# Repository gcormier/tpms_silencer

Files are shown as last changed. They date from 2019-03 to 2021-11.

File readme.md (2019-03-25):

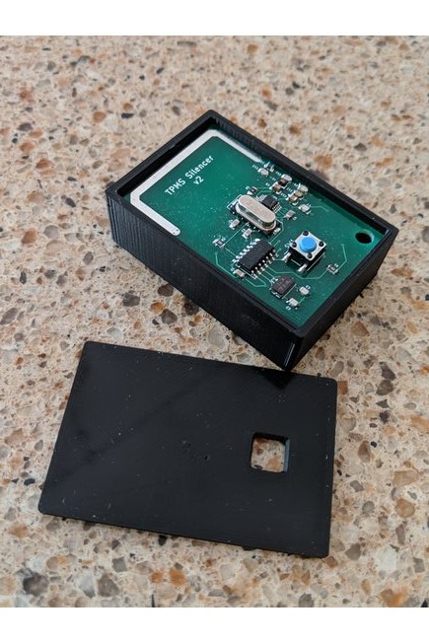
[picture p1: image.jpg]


# tpms_silencer
Open hardware that supports ASK/FSK transmit on 315/433MHz ISM bands. General point is to spoof TPMS sensors but
it could be used for any type of ASK/FSK transmittion on bands supported by the IC.

Big thanks to <a href="https://github.com/merbanan/rtl_433">rtl_433</a> project, wouldn't exist without their hard work for
decoding the TPMS in the first place.

## Availability
Boards are for sale https://www.tindie.com/products/gcormier/tpms-silencer/

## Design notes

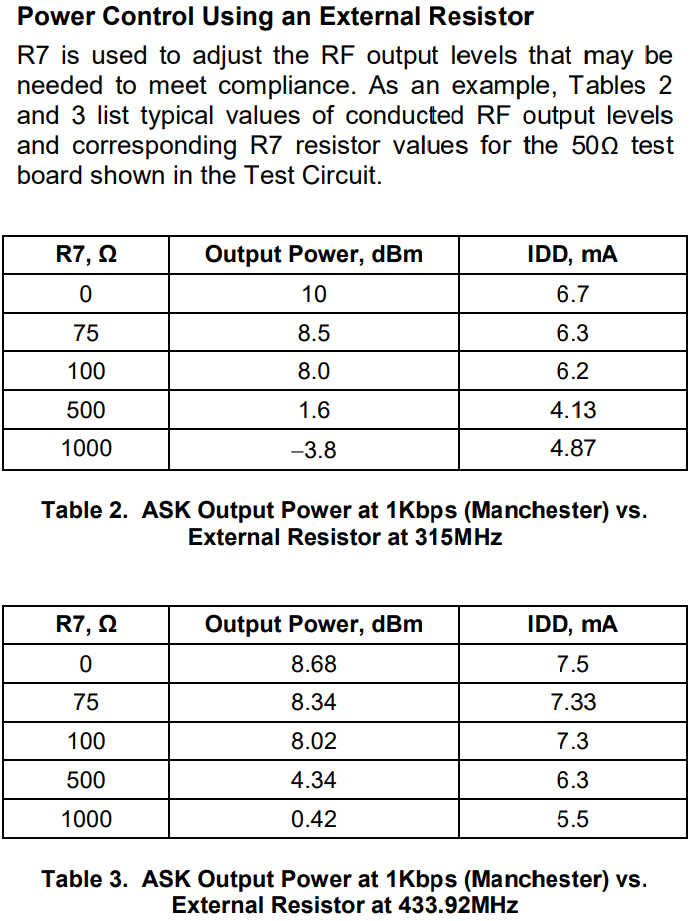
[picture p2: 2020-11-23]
PCB/values2.png

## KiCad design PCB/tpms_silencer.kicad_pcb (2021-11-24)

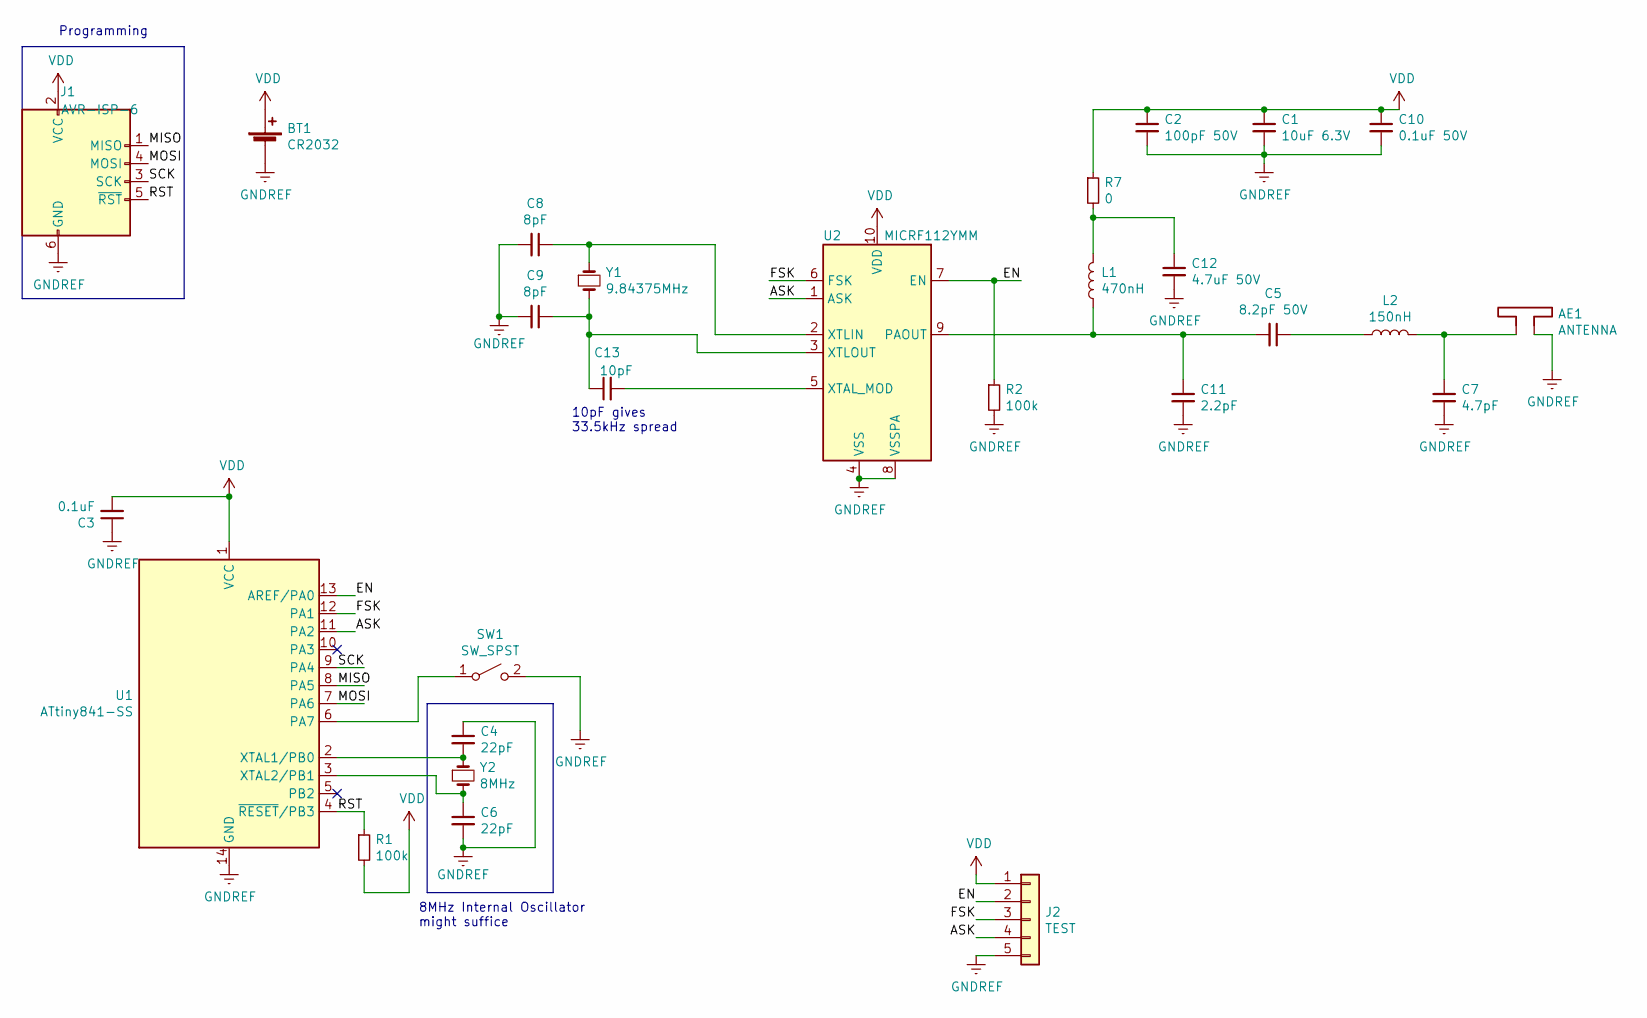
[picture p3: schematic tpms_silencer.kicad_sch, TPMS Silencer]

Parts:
AE1: ANTENNA; 315MHz Antenna
BT1: CR2032; BatteryHolder_Keystone_3034_1x20mm
C1: 10uF 6.3V; C_0805_2012Metric
C2: 100pF 50V; C_0805_2012Metric
C3: 0.1uF; C_0805_2012Metric
C4, C6: 22pF; C_0805_2012Metric
C5: 8.2pF 50V; C_0805_2012Metric
C7: 4.7pF; C_0805_2012Metric
C8, C9: 8pF; C_0805_2012Metric
C10: 0.1uF 50V; C_0805_2012Metric
C11: 2.2pF; C_0805_2012Metric
C12: 4.7uF 50V; C_0805_2012Metric
C13: 10pF; C_0805_2012Metric
J1: AVR-ISP-6; AVR-SMD-Programming-Header
J2: TEST; PinHeader_1x05_P2.54mm_Horizontal
L1: 470nH; L_0805_2012Metric
L2: 150nH; L_0805_2012Metric
R1, R2: 100k; R_0805_2012Metric
R7: 0; R_0805_2012Metric
SW1: SW_SPST; SW_SPST_PTS645
U1: ATtiny841-SS; SOIC-14_3.9x8.7mm_P1.27mm
U2: MICRF112YMM; MSOP-10_3x3mm_P0.5mm
Y1: 9.84375MHz; Crystal_SMD_HC49-SD
Y2: 8MHz; Crystal_SMD_TXC_7A-2Pin_5x3.2mm

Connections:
/ASK: J2.4, U1.11 (PA2), U2.1 (ASK)
/EN: J2.2, R2.1, U1.13 (AREF/PA0), U2.7 (EN)
/FSK: J2.3, U1.12 (PA1), U2.6 (FSK)
/MISO: J1.1 (MISO), U1.8 (PA5)
/MOSI: J1.4 (MOSI), U1.7 (PA6)
/RST: J1.5 (~RST), R1.1, U1.4 (~RESET/PB3)
/SCK: J1.3 (SCK), U1.9 (PA4)
GNDREF: AE1.2, BT1.2 (-), C1.2, C2.2, C3.1, C4.1, C6.2, C7.2, C8.2, C9.2, C10.2, C11.2, C12.2, J1.6 (GND), J2.5, R2.2, SW1.2 (B), U1.14 (GND), U2.4 (VSS), U2.8 (VSSPA)
unnamed: AE1.1, C7.1, L2.2
unnamed: C4.2, U1.2 (XTAL1/PB0), Y2.1
unnamed: C5.1, L2.1
unnamed: C6.1, U1.3 (XTAL2/PB1), Y2.2
unnamed: C8.1, U2.2 (XTLIN), Y1.1
unnamed: C5.2, C11.1, L1.1, U2.9 (PAOUT)
unnamed: C12.1, L1.2, R7.2
unnamed: C9.1, C13.1, U2.3 (XTLOUT), Y1.2
unnamed: C13.2, U2.5 (XTAL_MOD)
unnamed: SW1.1 (A), U1.6 (PA7)
VDD: BT1.1 (+), C1.1, C2.1, C3.2, C10.1, J1.2 (VCC), J2.1, R1.2, R7.1, U1.1 (VCC), U2.10 (VDD)

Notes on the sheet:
10pF gives 33.5kHz spread
8MHz Internal Oscillator might suffice
Programming

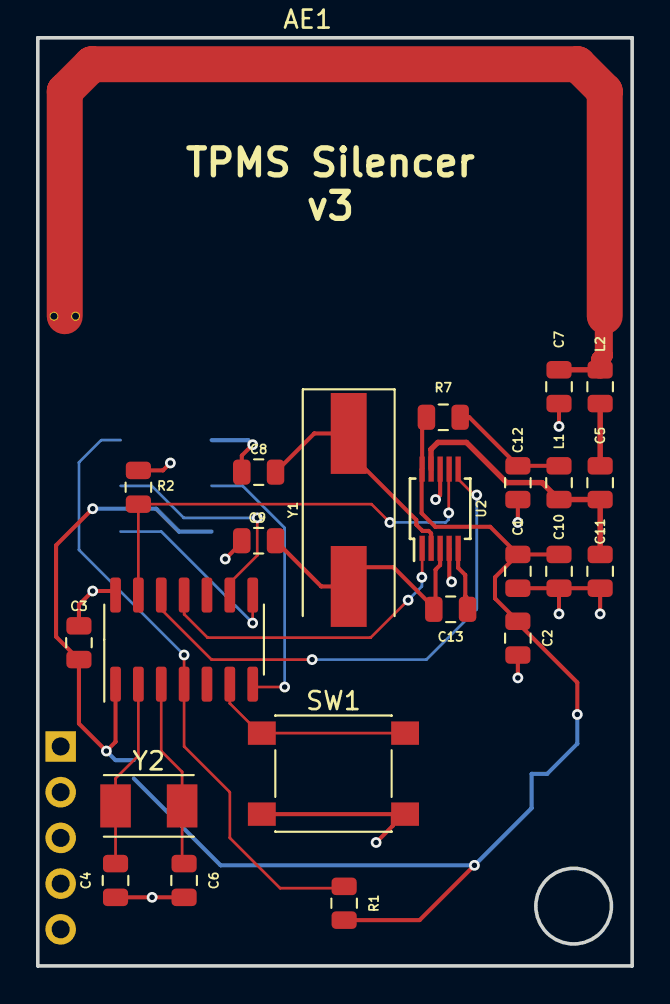
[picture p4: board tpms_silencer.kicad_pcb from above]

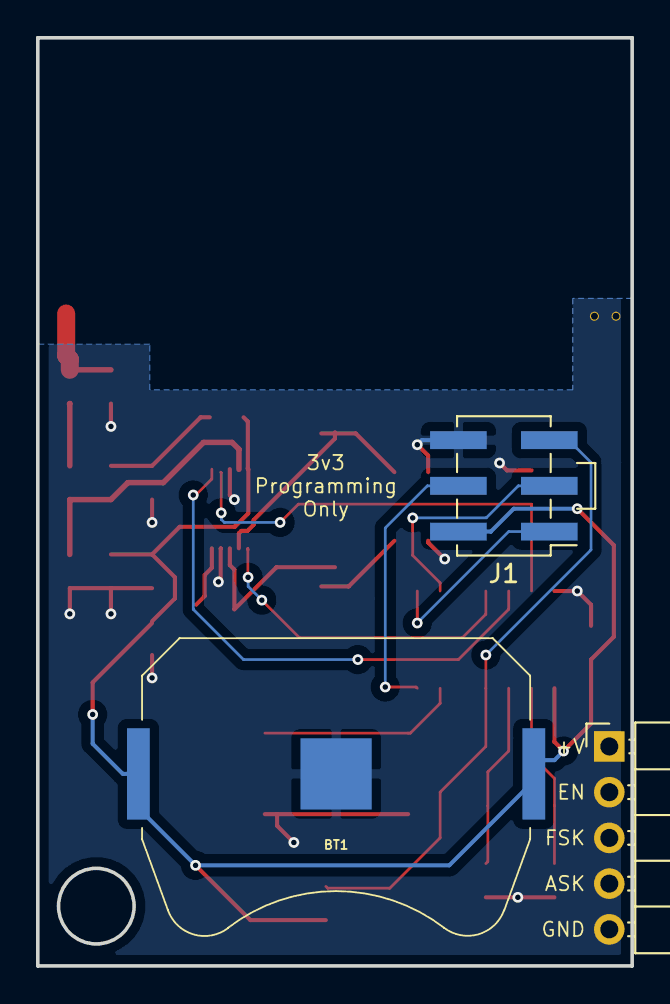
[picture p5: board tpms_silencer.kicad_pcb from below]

Board: 2 copper layers, 33.0 x 51.6 mm, 27 parts (3 on the bottom side), 19 nets.

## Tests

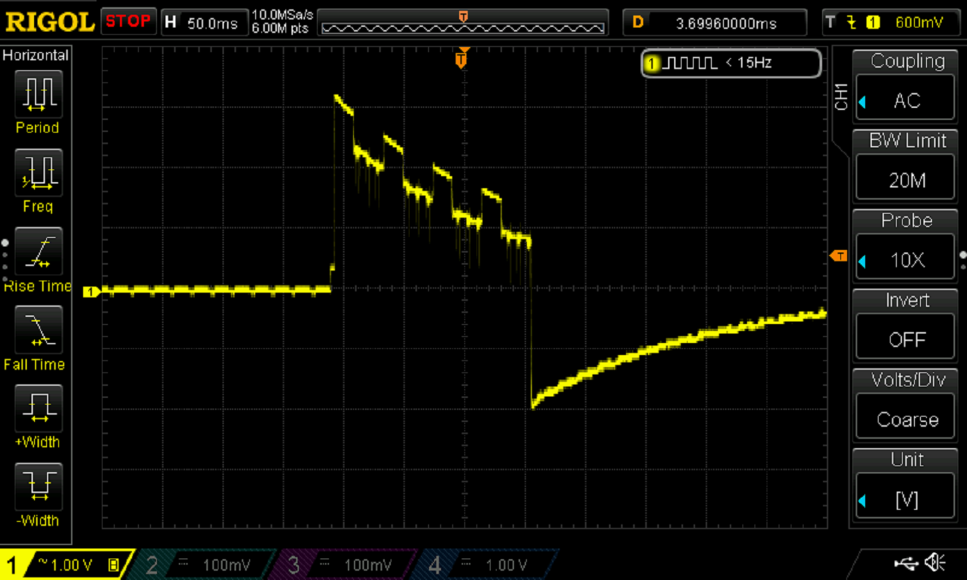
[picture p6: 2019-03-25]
Current Measurement.png

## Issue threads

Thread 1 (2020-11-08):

How to capture new TPMS data

StavJi, 2020-11-08:
Hello,

trying to decode raw data using rtl_433 SW. This is what I am sending: "111111001100110101010101010101010100101010110100110101001011001010101101010100101010101101010100110011010011010010101011010101001100110100101100"

On picture what I am decoding. I noticed that rtl trying to use PWM modulations but it should be FSK. Can you explain to me how to get back to your data? I supposed that you somehow captured TPMS message from car and I want to know how did you do that? Thank you for your help.

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

gcormier, 2020-11-08:
I captured using rtl_433 - https://github.com/merbanan/rtl_433/issues/821

I merely replay the encoded bitstream with tpms_silencer - I don't do any actual Manchester encoding on the transmitter. So you will want the raw-bitstream from rtl_433.

StavJi, 2020-11-21:
I figure it out, problem was that your sensors uses baudrate of 10000 so to capture raw bitstream using rtl_433 you need to use command: rtl_433 -R 0 -X "n=tpms,m=FSK_PCM,s=100,l=100,r=250". I think more common (my case) is sensors with baudrate 20000 so cmd will be: rtl_433 -R 0 -X "n=tpms,m=FSK_PCM,s=52,l=52,r=150".

Closed 2020-11-21.

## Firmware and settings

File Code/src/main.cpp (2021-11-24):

#include <avr/wdt.h>
#include <avr/power.h>
#include <avr/sleep.h>
#include <Arduino.h>
#include "tpms_silencer.h"

/*
Each bit/symbol: 0/1 is 100us long. sent at a rate of 10kHz
144 symbols sent in each TPMS packet: taking 14.4ms (+ 200us warmup)
All Packets are sent 40ms apart, then we deep-sleep.
If PERIODIC_TX is defined then wakeup after 7s * wakeuplimit (which is potentially variable)
BACKOFF will double the retransmit period each time until MAX_LIMIT.
*/

#define PIN_EN     A0  // PA0, Pin 13, Arduino 10
#define PIN_FSK    A1 // PA1, Pin 12, Arduino 9
#define PIN_ASK    A2 // PA2, Pin 11, Arduino 8
#define PIN_BUTTON A7 // PA7, Pin 6, PCINT7
#define INTERRUPT_PIN PCINT7 // interrupt for PA7

#define PERIODIC_TX // periodic retransmissions. disable for button-press tx only
//#define BACKOFF    // double transmit period everytime? disable to have a fixed period retrans.

#define ENHIGH (bitSet(PORTA, 0))
#define ENLOW (bitClear(PORTA, 0))

#define ASKHIGH (bitSet(PORTA, 2))
#define ASKLOW (bitClear(PORTA, 2))

#define FSKHIGH (bitSet(PORTA, 1))
#define FSKLOW (bitClear(PORTA, 1))
#define FSKTOGGLE (PORTA = PORTA ^ _BV(1))


#define PACKET_DELAY   40 // Milliseconds inter-packet period
#ifdef BACKOFF
#define LIMIT_START     1 // (re-transmit intervals: 14s, 28s, 56s, ..., MAX_LIMIT/7)
//#define MAX_LIMIT      80 // 80 max limit ~ 10mins.
#define MAX_LIMIT     160 // 160 max limit ~ 20 mins.
//#define MAX_LIMIT  0xffff // uint16_t max limit ~ 5 days.
#else
//#define LIMIT_START     8 //   8*(7s) = ~60s wakeups to transmit
#define LIMIT_START     120 // 120*(7s) = ~15mins wakeups to transmit
#endif

/*
captured tpms data: with rtl_433 -vv ...
time      : 2021-10-22 18:46:04
model     : PMV-107J     type      : TPMS          id        : 07698722
status    : 16           battery_ok: 1             counter   : 2             failed    : OK            pressure_kPa: 228.160     temperature_C: 13.000     mic       : CRC
pulse_demod_pcm(): PMV-107J (Toyota) TPMS
bitbuffer:: Number of rows: 1 
[00] {143} fc b3 4d 2b 2a b3 52 ad 4a ad 54 ab 32 ca cb 4d 2c ac 
_ _ _ _ _ _ _ _ _ _ _ _ _ _ _ _ _ _ _ _ _ _ _ _ _ _ _ _ _ _ _ _ _ _ _ _ _ _ _ _ _ _ _ _ _ _ _ _ _ _ _ _ _ _ _ _ _ _ _ _ _ _ _ _ _ _ _ _ _ _ _ _ _ _ _ _ _ _ _ _ _ _ _ _ _ _ _ _ _ _ _ _ _ _ _ _ _ _ _ _ _ _ _ _ _ _ _ _ _ _ _ _ _ _ _ _ _ _ _ _ _ _ _ _ _ _ _ _ _ _ _ _ _ _ _ _ _ _ _ _ _ _ _ _ _ _ _ _ _ _ _ _ _ _ _ _ _ _ _ _ 
time      : 2021-10-22 18:46:13
model     : PMV-107J     type      : TPMS          id        : 0805a722
status    : 24           battery_ok: 1             counter   : 3             failed    : OK            pressure_kPa: 220.720     temperature_C: 13.000     mic       : CRC
pulse_demod_pcm(): PMV-107J (Toyota) TPMS
bitbuffer:: Number of rows: 1 
[00] {143} fc d5 55 4b 2d 4c ad 52 b2 ad 55 4b 33 2a cb 4c cd 4c 
_ _ _ _ _ _ _ _ _ _ _ _ _ _ _ _ _ _ _ _ _ _ _ _ _ _ _ _ _ _ _ _ _ _ _ _ _ _ _ _ _ _ _ _ _ _ _ _ _ _ _ _ _ _ _ _ _ _ _ _ _ _ _ _ _ _ _ _ _ _ _ _ _ _ _ _ _ _ _ _ _ _ _ _ _ _ _ _ _ _ _ _ _ _ _ _ _ _ _ _ _ _ _ _ _ _ _ _ _ _ _ _ _ _ _ _ _ _ _ _ _ _ _ _ _ _ _ _ _ _ _ _ _ _ _ _ _ _ _ _ _ _ _ _ _ _ _ _ _ _ _ _ _ _ _ _ _ _ _ _ 
time      : 2021-10-22 18:46:14
model     : PMV-107J     type      : TPMS          id        : 0f536702
status    : 16           battery_ok: 1             counter   : 2             failed    : OK            pressure_kPa: 218.240     temperature_C: 13.000     mic       : CRC
pulse_demod_pcm(): PMV-107J (Toyota) TPMS
bitbuffer:: Number of rows: 1 
[00] {144} fc cc b4 ac b2 b3 55 52 b5 52 aa ab 33 35 34 b3 53 2c 
_ _ _ _ _ _ _ _ _ _ _ _ _ _ _ _ _ _ _ _ _ _ _ _ _ _ _ _ _ _ _ _ _ _ _ _ _ _ _ _ _ _ _ _ _ _ _ _ _ _ _ _ _ _ _ _ _ _ _ _ _ _ _ _ _ _ _ _ _ _ _ _ _ _ _ _ _ _ _ _ _ _ _ _ _ _ _ _ _ _ _ _ _ _ _ _ _ _ _ _ _ _ _ _ _ _ _ _ _ _ _ _ _ _ _ _ _ _ _ _ _ _ _ _ _ _ _ _ _ _ _ _ _ _ _ _ _ _ _ _ _ _ _ _ _ _ _ _ _ _ _ _ _ _ _ _ _ _ _ _ 
time      : 2021-10-22 18:46:14
model     : PMV-107J     type      : TPMS          id        : 00a89722
status    : 8            battery_ok: 1             counter   : 1             failed    : OK            pressure_kPa: 230.640     temperature_C: 14.000     mic       : CRC
pulse_demod_pcm(): PMV-107J (Toyota) TPMS
bitbuffer:: Number of rows: 1 
[00] {144} fc aa d2 d5 2b 4c ad 52 ad 52 ab 4b 32 d5 34 d5 2b 2c

*/


// Use the compact encoding reported by rtl_433 -vv  <-f 315M -R 110>
// could halve this by storing the Differential-Manchester decoded values...
// Or even better generate packets on the fly, based on id, pressure/temp, etc.
#define NO_PACKETS      4
#define PACKET_LEN     18
#define PACKETSIZE    (PACKET_LEN*8) // 144 bits
const unsigned char packets[NO_PACKETS][PACKET_LEN] = { 
  // packet 0
  { 0xfc, 0xb3, 0x4d, 0x2b, 0x2a, 0xb3, 0x52, 0xad, 0x4a, 0xad, 0x54, 0xab, 0x32, 0xca, 0xcb, 0x4d, 0x2c, 0xac},
  // packet 1
  { 0xfc, 0xd5, 0x55, 0x4b, 0x2d, 0x4c, 0xad, 0x52, 0xb2, 0xad, 0x55, 0x4b, 0x33, 0x2a, 0xcb, 0x4c, 0xcd, 0x4c},
  // packet 2
  { 0xfc, 0xcc, 0xb4, 0xac, 0xb2, 0xb3, 0x55, 0x52, 0xb5, 0x52, 0xaa, 0xab, 0x33, 0x35, 0x34, 0xb3, 0x53, 0x2c},
  // packet 3
  { 0xfc, 0xaa, 0xd2, 0xd5, 0x2b, 0x4c, 0xad, 0x52, 0xad, 0x52, 0xab, 0x4b, 0x32, 0xd5, 0x34, 0xd5, 0x2b, 0x2c} };

volatile unsigned char packet=0; // which packet is being sent 0 - NO_PACKETS-1
volatile unsigned int currentBit; // which bit in that packet is next

volatile bool transmitting = false; // indicates if transmitting a packet

volatile unsigned int wakeupCounter = 0; // how many 8s watchdog timeouts since last transmit
volatile unsigned int wakeuplimit = LIMIT_START;  // How many 8-second wakeups before transmit again


// setup functions

// 10khz Interrupt for an 8MHz clock
void setupInterrupt8()
{
  noInterrupts();
  // Clear registers
  TCCR1A = 0;
  TCCR1B = 0;
  TCNT1 = 0;

  // 10000 Hz (8000000/((99+1)*8))
  OCR1A = 99;
  // CTC
  TCCR1B |= (1 << WGM12);
  // Prescaler 8
  TCCR1B |= (1 << CS11);
  // Output Compare Match A Interrupt Enable
  TIMSK1 |= (1 << OCIE1A);

  // button interrupt
  PCMSK0 |= (1 << INTERRUPT_PIN);
  GIMSK |= (1 << PCIE0 );

  interrupts();
}

// 10khz Interrupt for a 16MHz clock
void setupInterrupt16()
{
  noInterrupts();
  // Clear registers
  TCCR1A = 0;
  TCCR1B = 0;
  TCNT1 = 0;

  // 10000 Hz (16000000/((24+1)*64))
  OCR1A = 24;
  // CTC
  TCCR1B |= (1 << WGM12);
  // Prescaler 64
  TCCR1B |= (1 << CS11) | (1 << CS10);
  // Output Compare Match A Interrupt Enable
  TIMSK1 |= (1 << OCIE1A);

  // button interrupt
  PCMSK0 |= (1 << INTERRUPT_PIN);
  GIMSK |= (1 << PCIE0 );

  interrupts();
}

void setup()
{
  for (byte i = 0; i < 13; i++)
    pinMode(i, INPUT);

  // disable ADC + other stuff that uses power
  ADCSRA = 0;
  power_spi_disable();
  power_usart0_disable();
  power_usart1_disable();
  power_timer2_disable();
  power_twi_disable();
  // find more in power.h

  pinMode(PIN_EN, OUTPUT);
  pinMode(PIN_FSK, OUTPUT);
  pinMode(PIN_ASK, OUTPUT);
  pinMode(PIN_BUTTON, INPUT_PULLUP);
  
#ifdef PERIODIC_TX
  /* Clear the reset flags. */
  MCUSR = 0;

  /* set watchdog interrupt with prescalers */
  WDTCSR = 1<<WDP0 | 1<<WDP3 | 1<<WDIE | 1<<WDE; /* 8.0 seconds */ 
#endif


#if F_CPU == 16000000L
  setupInterrupt16();
#elif F_CPU == 8000000L
  setupInterrupt8();
#else
#error CPU is not set to 16MHz or 8MHz!
#endif
  disableTX();

  wakeupCounter = wakeuplimit; // force an immediate transmit
}

// runtime functions

// 100 usec timer for bit tx
ISR(TIMER1_COMPA_vect)
{
  if (transmitting)
  {
    if (currentBit >= PACKETSIZE)
    {
      disableTX();
      return;
    }

    // read off bits in bigendian order
    if ( ( packets[packet][currentBit/8] & ( 0x80 >> (currentBit % 8) ) ) )
      FSKLOW;  // low signal - higher freq
    else
      FSKHIGH; // high signal - lower freq
    
    currentBit++;
  }
}

#ifdef PERIODIC_TX
// watchdog timer is setup by setupInterrupt8(). kicks roughly 7-8s at 3v.
ISR(WDT_vect)
{
  // reset WDIE to ensure next watchdog uses the interrupt too (dont reboot!)
  WDTCSR |= bit(WDIE);
  wakeupCounter++;
}
#endif

// button interrupt is setup by setupInterrupt8()
ISR(PCINT0_vect)
{
  // could use a +300ms debounce here, but its not critcal if we transmit packets twice...
  if( digitalRead(PIN_BUTTON) == LOW ) {
    // button press. wakeup, transmit and set initial retransmit period
    wakeuplimit = LIMIT_START;
    wakeupCounter = wakeuplimit;
  //} else {
    // button release
  }
}

// sleep until an WDT/button interrupt fires
void sleepyTime()
{
  // Just in case
  disableTX();

  set_sleep_mode(SLEEP_MODE_PWR_DOWN);

  sleep_enable();
  sleep_mode();
  sleep_disable();
}

// queue up and prepare to send a packet
void sendPacket(unsigned int which)
{
  packet = min( which, NO_PACKETS-1 );
  currentBit = 0;

  enableTX();
}

// warm-up transmitter and enable bit-period interrupt
void enableTX()
{
  FSKHIGH;
  ASKHIGH;
  ENHIGH;

  delayMicroseconds(200); // 200uS+ to wake up (similar to captured tpms)
  transmitting = true;
  power_timer1_enable();
}

// disable transmitter and disable bit-period interrupt
void disableTX()
{
  ENLOW;
  FSKHIGH;
  transmitting = false;
  power_timer1_disable();
}

void loop()
{
  if (wakeupCounter >= wakeuplimit)
  {
    for (int i=0; i<NO_PACKETS; i++) {
      sendPacket(i);
      delay(PACKET_DELAY);
    }

    // reset to wait for next tx
    wakeupCounter = 0;

#ifdef BACKOFF
    // double the wakeuplimit each time to back-off and save battery
    wakeuplimit *= 2;
#ifdef MAX_LIMIT
    // but only up to this limit:
    wakeuplimit = min(wakeuplimit, MAX_LIMIT);
#endif
#endif
  }

  sleepyTime();
}

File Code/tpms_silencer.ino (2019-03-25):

#include <avr/pgmspace.h>
#include <avr/wdt.h>
#include <avr/power.h>
#include <avr/sleep.h>

/*
 * Note to self:
 * DID YOU BURN THE BOOTLOADER?!?!
 * DID YOU SET THE FUSES PROPERLY?
 * Fuses OK (E:FE, H:D6, L:EE)
 * Low should be set to EE to reduce wakeup time
 * -U lfuse:w:0xEE:m -U hfuse:w:0xD6:m -U efuse:w:0xFE:m
 * C:\Users\Greg\AppData\Local\arduino15\packages\arduino\tools\avrdude\6.3.0-arduino14\bin\avrdude "-CC:\Users\Greg\AppData\Local\arduino15\packages\ATTinyCore\hardware\avr\1.2.1/avrdude.conf" -v -pattiny841 -cusbtiny -U lfuse:w:0xEE:m -U hfuse:w:0xD6:m -U efuse:w:0xFE:m
 * 
 * MAKE SURE to check for over 100% memory usage after compiling!
 */


#define PIN_EN        A0   // PA0, Pin 13, Arduino 10
#define PIN_FSK       A1   // PA1, Pin 12, Arduino 9
#define PIN_ASK       A2   // PA2, Pin 11, Arduino 8

#define FSKLOW        (bitSet(PORTA, 1))
#define FSKHIGH       (bitClear(PORTA, 1))
#define FSKTOGGLE     (PORTA = PORTA ^ _BV(1))

#define PACKETSIZE    144

#define PACKET_DELAY  25   // Milliseconds between packets
#define WAKEUPCOUNT   16     // How make 8-second wakeups before transmit

const char PROGMEM packetOne[] = "111111001100110101010101010101010100101010110100110101001011001010101101010100101010101101010100110011010011010010101011010101001100110100101100";
const char PROGMEM packetTwo[] = "111111001011001100101011001100101010101101001011001011010101010101001010101011010101010100110100110011001010101101010101001100101010101010101100";
const char PROGMEM packetFour[] = "111111001100110010101010101011010010101010110100110101001011001101010010101011010101010101010100110011001100101101010101010011001100110101001100";
const char PROGMEM packetThree[] = "111111001011001010110011010010101100110101001011001010110100101101001101010100101010101011010100110011001011010010101011010101001101010010101100";

// Allocate the memory
char currentPacket[] = "111111001100110010101010101011010010101010110100110101001011001101010010101011010101010101010100110011001100101101010101010011001100110101001100";

volatile unsigned int currentPos;
volatile bool transmitting = false;
volatile int wakeupCounter = 0;


// Interrupt for 10khz for an 8MHz clock
void setupInterrupt8()
{
  noInterrupts();
  // Clear registers
  TCCR1A = 0;
  TCCR1B = 0;
  TCNT1 = 0;

  // 10000 Hz (8000000/((99+1)*8))
  OCR1A = 99;
  // CTC
  TCCR1B |= (1 << WGM12);
  // Prescaler 8
  TCCR1B |= (1 << CS11);
  // Output Compare Match A Interrupt Enable
  TIMSK1 |= (1 << OCIE1A);
  interrupts();
}

// Interrupt for 10khz for a 16MHz clock
void setupInterrupt16()
{
  noInterrupts();
  // Clear registers
  TCCR1A = 0;
  TCCR1B = 0;
  TCNT1 = 0;

  // 10000 Hz (16000000/((24+1)*64))
  OCR1A = 24;
  // CTC
  TCCR1B |= (1 << WGM12);
  // Prescaler 64
  TCCR1B |= (1 << CS11) | (1 << CS10);
  // Output Compare Match A Interrupt Enable
  TIMSK1 |= (1 << OCIE1A);
  interrupts();
}

void setup()
{
  // TODO: Unsure if INPUT or INPUT_PULLUP gives lowest power consumption.
  for (byte i = 0; i < 13; i++)
    pinMode(i, INPUT);

  // disable ADC
  ADCSRA = 0;

  pinMode(PIN_EN, OUTPUT);
  pinMode(PIN_FSK, OUTPUT);
  pinMode(PIN_ASK, OUTPUT);
  
  disableTX();

#if F_CPU == 16000000L
  setupInterrupt16();
#elif F_CPU == 8000000L
  setupInterrupt8();
#else
#error CPU is not set to 16MHz or 8MHz!
#endif
  wakeupCounter = 254;  // This will force a transmit when powered on, helps with debug
}


ISR(TIMER1_COMPA_vect)
{
  if (transmitting)
  {
    if (currentPacket[currentPos] == '1')
      FSKHIGH;
    else
      FSKLOW;

    if (++currentPos > PACKETSIZE)
    {
      transmitting = false;
      disableTX();
    }
  }

}

ISR(WDT_vect)
{
  wakeupCounter++;
  wdt_disable();  // disable watchdog
}

void sleepyTime()
{
  // Just in case
  disableTX();
  
  // disable ADC
  ADCSRA = 0;

  power_spi_disable();
  power_usart0_disable();
  power_timer2_disable();
  power_twi_disable();
  
  // clear various "reset" flags
  MCUSR = 0;
  
  // allow changes, disable reset
  WDTCSR = bit(WDE);
  
  // set interrupt mode and an interval 
  WDTCSR = bit(WDIE) | bit(WDP3) | bit(WDP0);    // set WDIE, and 8 seconds delay
  wdt_reset();  // pat the dog

  set_sleep_mode(SLEEP_MODE_PWR_DOWN);
  noInterrupts();           // timed sequence follows
  sleep_enable();
  interrupts();             // guarantees next instruction executed
  sleep_cpu();
}

void sendPacket(const char *thePacket)
{
  memcpy_P(currentPacket, thePacket, PACKETSIZE);

  currentPos = 0;

  enableTX();
  transmitting = true;
}

void loop()
{
  if (wakeupCounter > WAKEUPCOUNT)
  {
    wakeupCounter = 0;

    sendPacket((char *)packetOne);
    while (transmitting)
      __asm__("nop\n\t");
    delay(PACKET_DELAY);

    sendPacket(packetTwo);
    while (transmitting)
      __asm__("nop\n\t");
    delay(PACKET_DELAY);

    sendPacket(packetThree);
    while (transmitting)
      __asm__("nop\n\t");
    delay(PACKET_DELAY);

    sendPacket(packetFour);
    while (transmitting)
      __asm__("nop\n\t");
    delay(PACKET_DELAY);
  }

  sleepyTime();

}

void enableTX()
{
  FSKLOW;
  digitalWrite(PIN_ASK, HIGH);
  digitalWrite(PIN_EN, HIGH);
  delay(1); //1mS to wake up
}

void disableTX()
{
  FSKLOW;
  digitalWrite(PIN_ASK, LOW);
  digitalWrite(PIN_EN, LOW);

}

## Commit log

2018-11-13 Change programming header, comments on capacitor, v2 layout, hole for mounting in enclosure
    [tpms_silencer.kicad_pcb, tpms_silencer.sch]
2018-12-03 V2 - sent for fab.
    [tpms_silencer-B.Mask.gbs, tpms_silencer-B.Paste.gbp, tpms_silencer-B.SilkS.gbo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]
2019-03-25 Prep for release.
    [tpms_silencer-B.Mask.gbs, tpms_silencer-B.Paste.gbp, tpms_silencer-B.SilkS.gbo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]
2020-11-23 add test points and update annotation to match MICRF112-315-EV
    [tpms_silencer.kicad_pcb]
2021-11-21 compact packets, poweroff timer1 between packets
2021-11-24 update to kicad v6
    [tpms_silencer.kicad_pcb, tpms_silencer.kicad_sch, tpms_silencer.sch]
